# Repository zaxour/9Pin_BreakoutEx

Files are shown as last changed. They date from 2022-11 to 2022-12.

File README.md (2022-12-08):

# 9Pin_BreakoutEx
Breakout board for 9 pin mini DIN connectors with additional features for audio and sync.

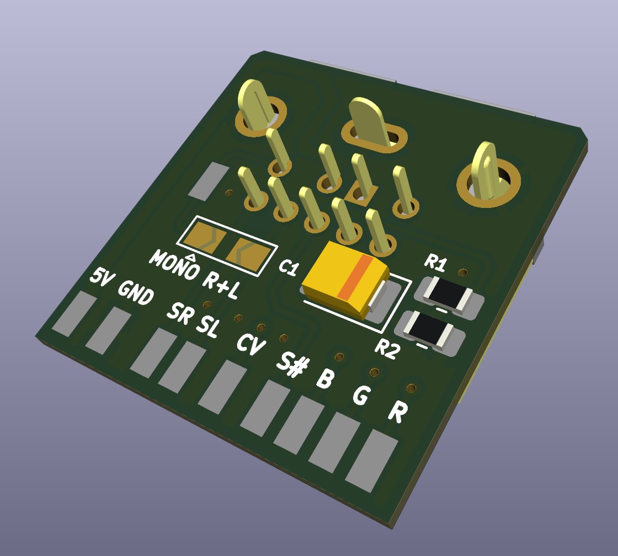
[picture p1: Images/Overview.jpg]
9P Breakout Isometric View


Leaving the jumpers un-bridged and components empty means the board will act like a standard 9 pin breakout DIN.

If attaching to a system that doesn't have composite and only has a 5V TTL level sync, use the following BOM:

C1: 220uF 6.3V Tantalum 3528 size capacitor
R1: 620 Ohm 1/8W 0603 size Resistor
R2: 86.6 Ohm 1/8 0603 size Resistor

RGB mods for older consoles tend to make the user decide between Composite Video level sync or TTL sync. With this breakout, simply install the resistors and capacitor (value indicated on bottom silkscreen) and use the TTL sync from the RGB modification. This will simultaneously deliver a proper sync voltage to the Composite Video pin on the DIN for using HD Retrovision cables. ***ENSURE THE RGB MOD CAN DRIVE TWO 75 OHM LOADS (Such as THS7374, THS7314 or similar) ***

The solder jumper for audio can be used as follows:
-Right: Connects Right and Left audio nodes, passes to both pins.
-Left: Connects Right audio to the Mono pin

Both jumpers can be soldered to make sure a mono audio signal goes to all of the audio pins.

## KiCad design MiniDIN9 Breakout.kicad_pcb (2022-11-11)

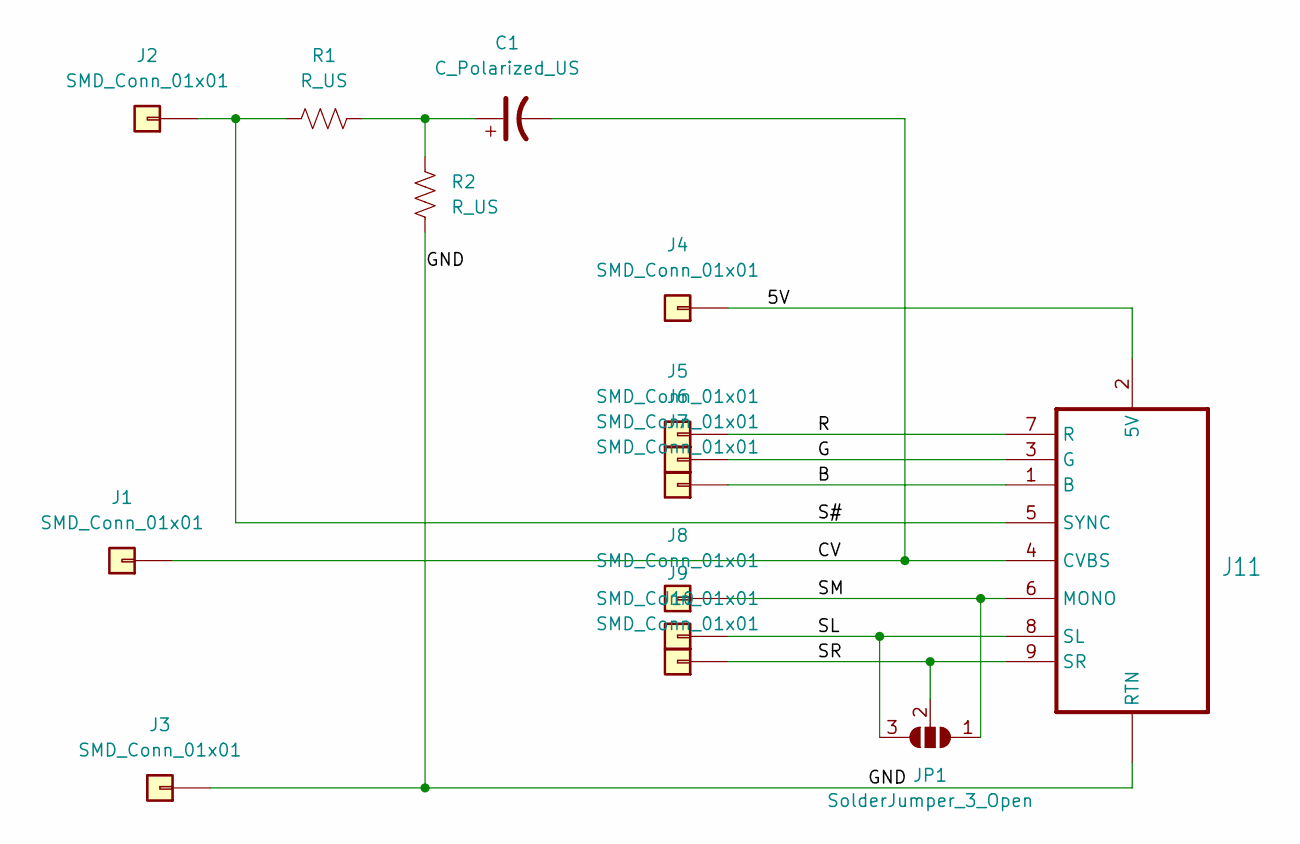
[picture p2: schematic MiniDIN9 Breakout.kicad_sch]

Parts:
C1: C_Polarized_US
J1, J2, J3, J4, J5, J6, J7, J8, J9, J10: SMD_Conn_01x01; SolderWirePad_1x01_SMD_1x2mm
J11: MD-90SM_MD2; CUI_MD-90SM
JP1: SolderJumper_3_Open; SolderJumper-3_P2.0mm_Open_TrianglePad1.0x1.5mm
R1, R2: R_US

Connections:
/5V: J4.1, J11.2 (5V)
/B: J7.1, J11.1 (B)
/CV: C1.2, J1.1, J11.4 (CVBS)
/G: J6.1, J11.3 (G)
/GND: J3.1, J11.S1 (RTN), J11.S2 (RTN), J11.S3 (RTN), R2.1
/R: J5.1, J11.7 (R)
/S#: J2.1, J11.5 (SYNC), R1.1
/SL: J9.1, J11.8 (SL), JP1.3 (B)
/SM: J8.1, J11.6 (MONO), JP1.1 (A)
/SR: J10.1, J11.9 (SR), JP1.2 (C)
unnamed: C1.1, R1.2, R2.2

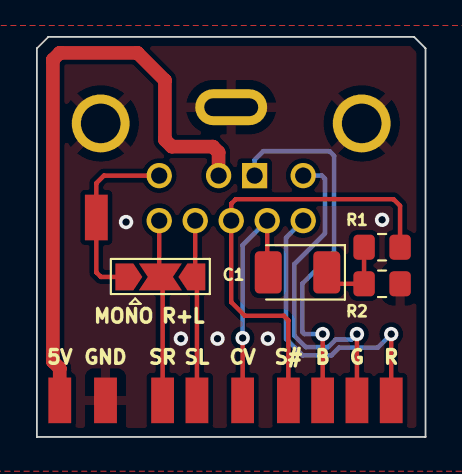
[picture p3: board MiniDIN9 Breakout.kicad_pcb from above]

Board: 2 copper layers, 21.6 x 22.2 mm, 15 parts (1 on the bottom side), 11 nets.
